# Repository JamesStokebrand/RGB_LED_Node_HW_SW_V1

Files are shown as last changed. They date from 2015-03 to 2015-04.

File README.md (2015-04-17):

RGB LED Controller and Node Project Version 1:

This is the Software/Hardware for the Node.

parts_list:
- Parts list pulled from EagleCAD project.
- Parts list spreadsheet listing quantity, parts numbers and supplier URLs.

src_code:
- CPP source code:
  * Makefile for AVR ATmega328p
  * XBee UART Driver and Communication wrapper
  * Support for AVR sleep and power reduction
  * Software based PWM (Timer based)
  * RGB Node State Machine
  * Color support for RGB and HSL color modes.

pcb_details:
- PCB Top/Bottom PNGs
- Eagle CAD schematic

PCBs are available for order on OSH Park:
https://oshpark.com/shared_projects/6Eqv3vIh

project_case:
- project case files in STL format with associated photos

Further information on this project can be found here:
https://jamesstokebrand.wordpress.com/category/rgb-led-controller-and-node-v1/

14 Mar 2015 - Initial Commit

23 Mar 2015 - Added Schematics and Project Cases 

17 Apr 2015 - Updated source code to use additional sleep methods. Fixed issues with RGB color classes and color conversions.

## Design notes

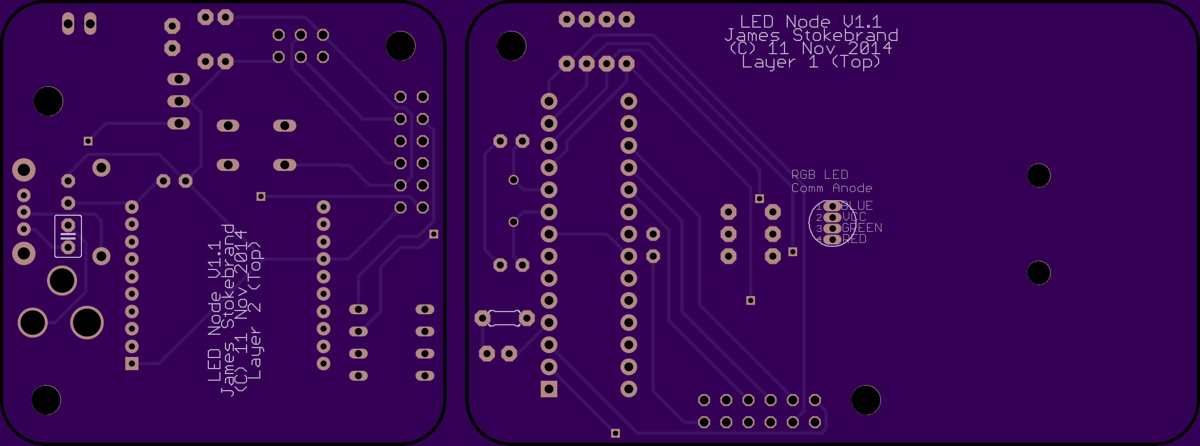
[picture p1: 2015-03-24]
pcb_details/Node_PCB_Top_V1.png

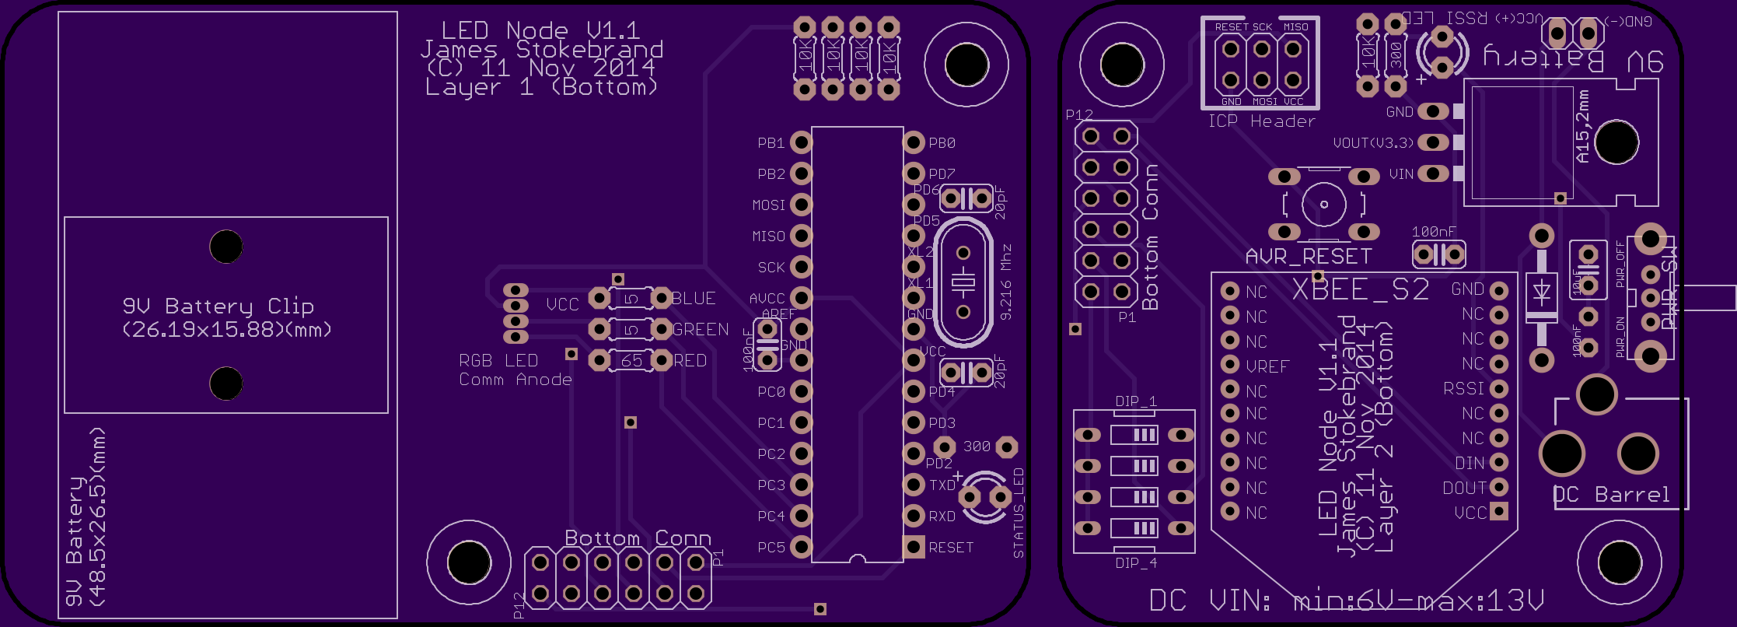
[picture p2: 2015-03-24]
pcb_details/Node_PCB_Bottom_V1.png

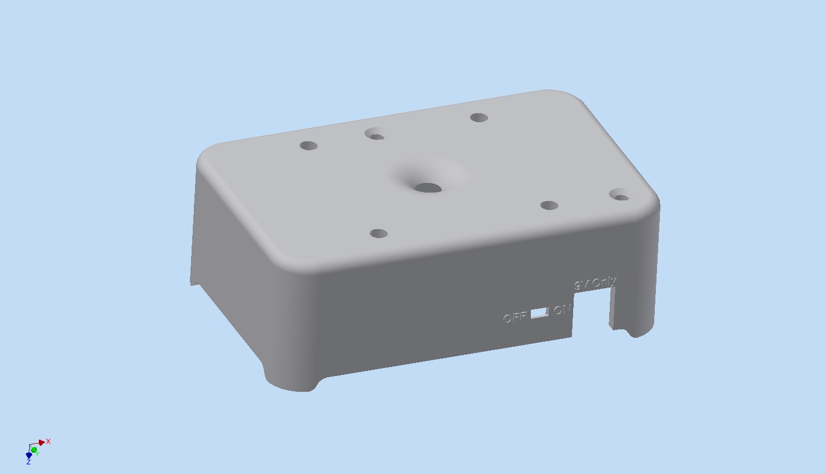
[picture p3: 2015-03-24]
project_case/Node_Shell_V1.jpg

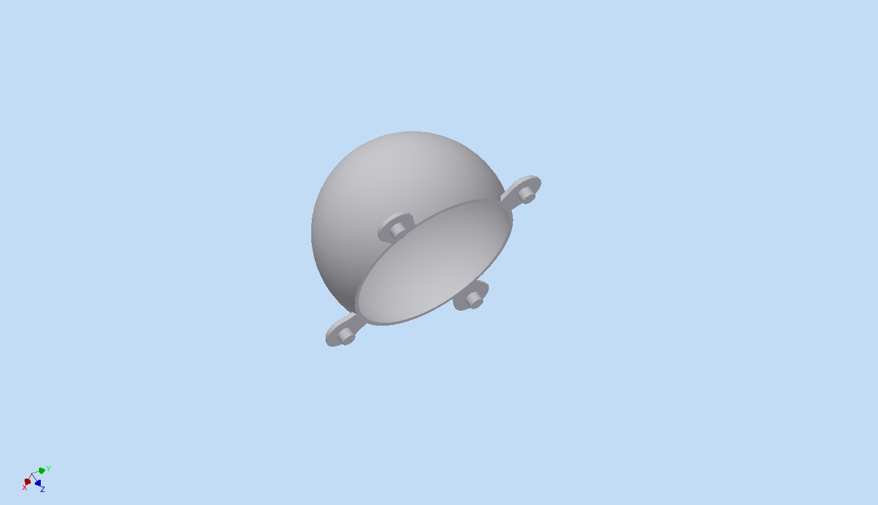
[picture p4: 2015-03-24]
project_case/Node_Globe_V1.jpg

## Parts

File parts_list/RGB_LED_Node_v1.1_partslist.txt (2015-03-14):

Partlist

Exported from RGB_LED_Node_v1.0.brd at 11/11/14 9:02 AM

EAGLE Version 6.6.0 Copyright (c) 1988-2014 CadSoft

Assembly variant: 

Part       Value                   Package        Library                       Position (inch)       Orientation

C1         100nF                   C025-030X050   adafruit                      (5.75 0.99)           MR90
C2         10uF                    C025-030X050   adafruit                      (5.75 1.19)           R270
C3         100nF                   C025-024X044   adafruit                      (3.21 0.95)           R270
C4         20pF                    C025-024X044   adafruit                      (3.85 0.86)           R0
C9         20pf                    C025-024X044   adafruit                      (3.85 1.42)           R0
C13        100nF                   C025-024X044   adafruit                      (5.27 1.24)           R0
CN1        DC Barrel Jack          DCJACK_2MM_PTH adafruit                      (6.2 0.6)             R90
D1         1N4004                  DO41-10        adafruit                      (5.6 1.1)             R90
D2         LED-RGB-CA-THRUDIFFUSE  LED-RGB-THRU   SparkFun-LED                  (2.4 1.05)            MR90
IC1        LD117AV33               TO220L1        v-reg                         (5.4 1.6)             R270
ICP_HEADER                         2X03           pinhead                       (4.7 1.85)            R180
JP1                                2X06           pinhead                       (2.73 0.2)            R180
JP2                                2X06           pinhead                       (4.2 1.37)            R90
JP5                                1X02           pinhead                       (5.7 1.95)            R0
LED7       3mm RED                 LED3MM         adafruit                      (5.28 1.89)           R90
LED8       3mm RED                 LED3MM         adafruit                      (3.91 0.46)           R0
R1         68 Ohm                  0204/5         adafruit                      (2.77 1.1)            R180
R2         5 Ohm                   0204/5         adafruit                      (2.77 1)              R180
R3         10K                     0204/5         adafruit                      (3.33 1.87)           R90
R4         5 Ohm                   0204/5         adafruit                      (2.77 0.9)            R180
R5         10K                     0204/5         adafruit                      (3.42 1.87)           R90
R6         10K                     0204/5         adafruit                      (3.51 1.87)           R90
R7         10K                     0204/5         adafruit                      (3.6 1.87)            R90
R9         10K Ohm                 0204/5         adafruit                      (5.04 1.88)           R90
R14        300 Ohm                 0204/5         adafruit                      (3.88 0.62)           MR180
R21        300 Ohm                 0204/5         adafruit                      (5.13 1.88)           R90
S2         RESET                   B3F-10XX       switch-omron                  (4.9 1.4)             R0
S6         EG1213                  EG1213         adafruit                      (5.95 1.1)            R90
SW1                                EDG-04         special                       (4.29 0.51)           R90
U1         ATMEGA328P-PU-1030050P1 DIP28          OPL_Eagle_Library_Seeed_Sudio (3.5 0.95)            R180
XBEE       XBEE                    XBEE           adafruit                      (5.03 0.63)           R180
Y1          9.216 Mhz              HC49U-V        SparkFun-FreqCtrl             (3.84 1.15)           R90

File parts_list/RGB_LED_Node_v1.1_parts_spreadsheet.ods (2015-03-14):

11/11/14 | RGB LED Node Board V1.1
Count | Part Name/Description | Pins/Pkg | Pin Spacing | Manuf Part # | Supplier | Supplier Part # | Price Ea (~) | Total | URL
1 | 3.3v Voltage Regulator | 3 | 0.1”(2.54mm) | LD1117V33 | Digikey | 497-1491-5-ND | 0.64 | 0.64 | http://www.digikey.com/product-detail/en/LD1117V33/497-1491-5-ND/586012
3 | CAP CER 0.1UF 25V RADIAL (100nF) | 2 | 0.1”(2.54mm) | FK18X7R1E104K | Digikey | 445-8421-ND | 0.29 | 0.87 | http://www.digikey.com/product-detail/en/FK18X7R1E104K/445-8421-ND/2815351
2 | CAP CER 20PF 50V 5% RADIAL | 2 | 0.1”(2.54mm) | C317C200J5G5TA | Digikey | 399-8916-ND | 0.51 | 1.02 | http://www.digikey.com/product-detail/en/C317C200J5G5TA/399-8916-ND/3522973
1 | CAP CER 10UF 25V 10% RADIAL | 2 | 0.1”(2.54mm) | FK16X7R1E106K | Digikey | 445-8351-ND | 0.65 | 0.65 | http://www.digikey.com/product-detail/en/FK16X7R1E106K/445-8351-ND/2815281
1 | CRYSTAL 9.216MHZ 20PF THRU | 2 | 4.8mm | ECS-92.1-20-4X | Digikey | X1096-ND | 0.81 | 0.81 | http://www.digikey.com/product-detail/en/ECS-92.1-20-4X/X1096-ND/827587
1 | LED SS RED DIFFUSED PCB 3MM | 2 | 0.1”(2.54mm) | MV50640 | Digikey | 1080-1100-ND | 0.42 | 0.42 | http://www.digikey.com/product-detail/en/MV50640/1080-1100-ND/2675591
1 | LED SS YELLOW DIFFUSED PCB 3MM | 2 | 0.1”(2.54mm) | MV5374C | Digikey | 1080-1106-ND | 0.46 | 0.46 | http://www.digikey.com/product-detail/en/MV5374C/1080-1106-ND/2675597
2 | RES 300 OHM 1/4W 1% AXIAL | 2 | 0.1”(2.54mm) | RNMF14FTC300R | Digikey | S300CACT-ND | 0.14 | 0.28 | http://www.digikey.com/product-detail/en/RNMF14FTC300R/S300CACT-ND/2617485
1 | SWITCH TACTILE SPST-NO 0.05A 24V | 4 | 6.5mmX4.5mm | B3F-1020 | Digikey | SW402-ND | 0.41 | 0.41 | http://www.digikey.com/product-detail/en/B3F-1020/SW402-ND/44059
1 | SWITCH SLIDE SPDT 30V RT ANGLE | 4 | Various | EG1213 | Digikey | EG1906-ND | 0.58 | 0.58 | http://www.digikey.com/product-detail/en/EG1213/EG1906-ND/101735
1 | ATMEGA328P-PU (IC MCU 8BIT 32KB FLASH 28DIP) | DIP28 | 0.1”(2.54mm) | ATMEGA328P-PU | Digikey | ATMEGA328P-PU-ND | 3.74 | 3.74 | http://www.digikey.com/product-detail/en/ATMEGA328P-PU/ATMEGA328P-PU-ND/1914589
1 | CONN IC SOCKET VERT 28POS TIN | DIP28 | 0.1”(2.54mm) | ED281DT | Digikey | ED3050-5-ND | 0.31 | 0.31 | http://www.digikey.com/product-detail/en/ED281DT/ED3050-5-ND/4147600
1 | DC Barrel Power Jack/connector | 3 | 4.7mm | PJ-002A | Digikey | CP-002A-ND | 0.93 | 0.93 | http://www.digikey.com/product-detail/en/PJ-002A/CP-002A-ND/96962
1 | DIODE GEN PURPOSE 50V 1A DO41 | 2 | N/A | 1N4001-TP | Digikey | 1N4001-TPMSCT-ND | 0.11 | 0.11 | http://www.digikey.com/product-detail/en/1N4001-TP/1N4001-TPMSCT-ND/773688
5 | RES 10K OHM 1/4W 1% AXIAL | 2 | 0.1”(2.54mm) | RNMF14FTC10K0 | Digikey | S10KCACT-ND | 0.14 | 0.7 | http://www.digikey.com/product-detail/en/RNMF14FTC10K0/S10KCACT-ND/2617809
1 | MODULE ZIGBEE W/WIRED ANT | 20 | 0.079”(2mm) | XB24-Z7WIT-004 | Digikey | 602-1098-ND | 17 | 17 | http://www.digikey.com/product-detail/en/XB24-Z7WIT-004/602-1098-ND/1942304
2 | CONN RECEPT 2MM SINGLE STR 10POS (1x10 2mm strip XBEE Socket) | 10 | 0.079”(2mm) | NPPN101BFCN-RC | Digikey | S5751-10-ND | 1.23 | 2.46 | http://www.digikey.com/product-detail/en/NPPN101BFCN-RC/S5751-10-ND/804812
1 | CONN HEADER 6POS 2.54 (2x3) | 2x3 | 0.1”(2.54mm) | 61200621621 | Digikey | 732-5394-ND | 0.82 | 0.82 | http://www.digikey.com/product-detail/en/61200621621/732-5394-ND/4846913
1 | CONN HEADER FMAL 12PS .1" DL TIN (2x6) | 2x6 | 0.1”(2.54mm) | PPTC062LFBN-RC | Digikey | S7074-ND | 0.98 | 0.98 | http://www.digikey.com/product-detail/en/PPTC062LFBN-RC/S7074-ND/810212
1 | Header, straight, 0.1”(2.54mm) pitch, male 5.84mm high (2x36 pin headers) | 2x36 | 0.1”(2.54mm) | 67996-472HLF | Digikey | 609-3494-ND | 1.45 | 1.45 | http://www.digikey.com/product-detail/en/67996-472HLF/609-3494-ND/1486045
1 | 9V SNAP I STYLE 3" WIRE LEADS | 2 | 0.1”(2.54mm) | BS3I | Digikey | BS3I-ND | 0.59 | 0.59 | http://www.digikey.com/product-detail/en/BS3I/BS3I-ND/2439485
1 | SWITCH DIP EXT ACTUATOR 4POS 24V | 8 | 0.1”(2.54mm) | 1825057-3 | Digikey | 450-1364-ND | 0.76 | 0.76 | http://www.digikey.com/product-detail/en/1825057-3/450-1364-ND/969174
1 | HOLDER BATTERY 9 VOLT STEEL | N/A | N/A | 71 | Digikey | 71K-ND | 0.42 | 0.42 | http://www.digikey.com/product-detail/en/71/71K-ND/1532224
2 | RES 5.1 OHM 1/4W 5% CF MINI | 2 | 1.7mm | CFM14JT5R10 | Digikey | S5.1QCT-ND | 0.1 | 0.2 | http://www.digikey.com/product-detail/en/CFM14JT5R10/S5.1QCT-ND/2617777
1 | RES 68 OHM 1/4W 1% AXIAL | 2 | 1.7mm | RNMF14FTC68R0 | Digikey | S68CACT-ND | 0.14 | 0.14 | http://www.digikey.com/product-detail/en/RNMF14FTC68R0/S68CACT-ND/2617528
1 | LED - RGB Diffused Common Anode | 4 | UNK | COM-10821 | Sparkfun | COM-10821 | 1.95 | 1.95 | https://www.sparkfun.com/products/10821
 | On Hand |  |  |  |  |  |  | 38.7
 | Ordered from Digikey
 | Updated parts list for RGB LED Node Board V1.1
 | - Removed four 2K Resistors and replaced with four 10K resistors.
 | NOTE : Maybe replace the 300 Ohm with 220 Ohm to better match the LEDs.!
 | Something like this:
 | RES 220 OHM 1/8W 5% CF AXIAL | 2 | 0.1”(2.54mm) | CF18JT220R | Digikey | CF18JT220RCT-ND | 0.1 |  | http://www.digikey.com/product-detail/en/CF18JT220R/CF18JT220RCT-ND/2022726

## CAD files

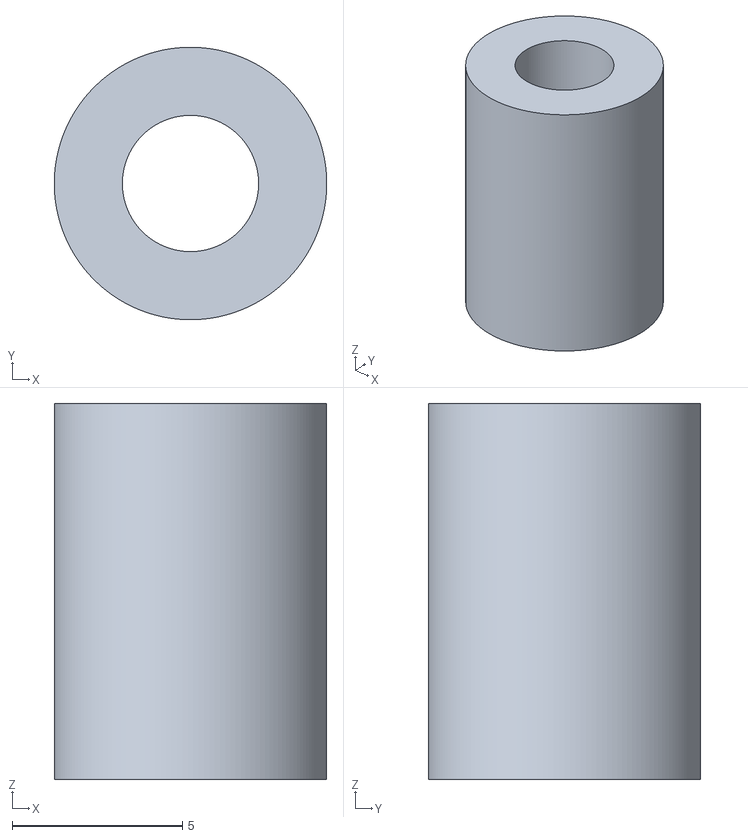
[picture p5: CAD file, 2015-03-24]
project_case/PCB_Spacer.stl
8.00 x 8.00 x 11.0

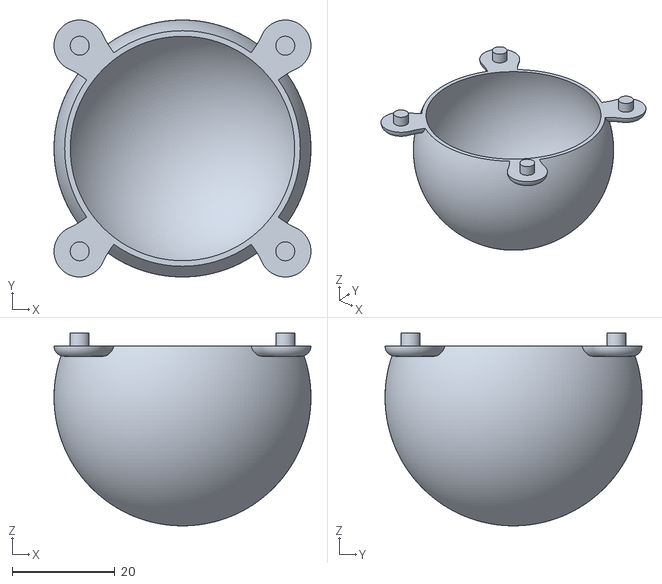
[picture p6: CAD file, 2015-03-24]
project_case/Node_Globe_V1.stl
50.0 x 50.0 x 37.5

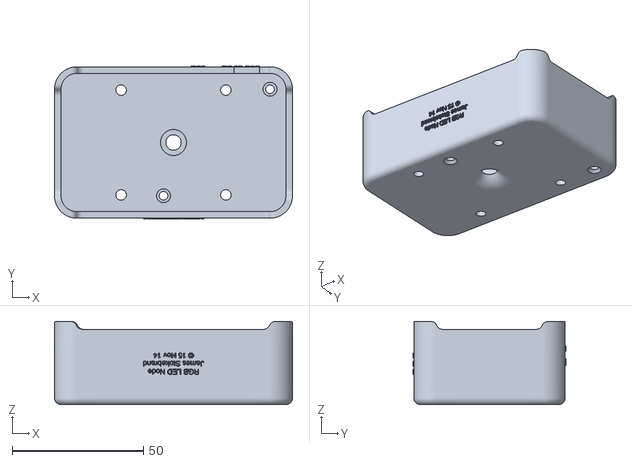
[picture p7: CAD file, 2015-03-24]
project_case/Node_Shell_V1.stl
90.8 x 58.5 x 31.7

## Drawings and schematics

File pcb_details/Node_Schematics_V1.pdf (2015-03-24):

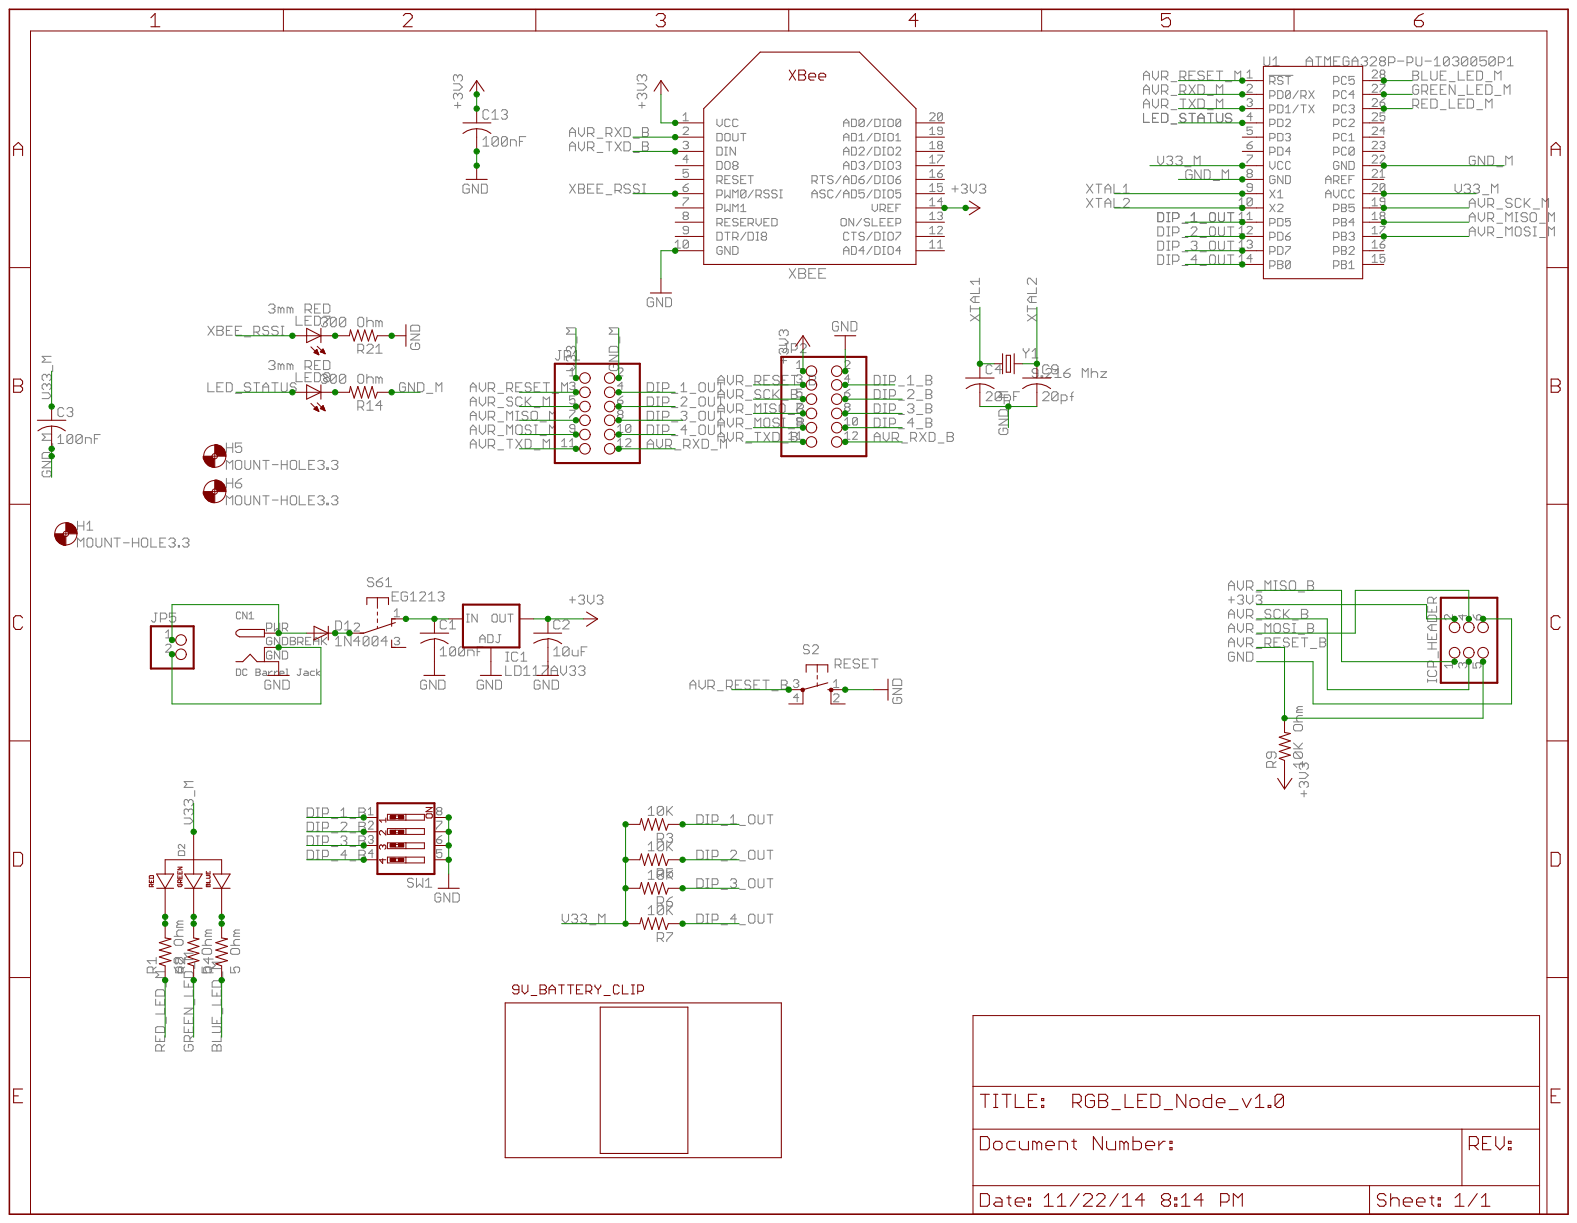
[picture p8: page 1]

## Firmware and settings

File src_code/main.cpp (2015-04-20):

/****************************************************
    RGB LED Node v1 hardware

    File:   main.cpp
    Author: James Stokebrand
    jamesstokebrand AT gmail DOT com
	
    main.cpp file is part of the RGB LED Controller and Node 
     version 1 hardware project.

    This file contains the main() method and the forever loop.  It 
     creates the RGB Node State machine and the code to sleep the AVR
     chip.
     
    Copyright (C) 2015 - James Stokebrand - 2015 Mar 12

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
    Rev History:
     When         Who                Description of change
    -----------  ----------         ------------------------
    2014 Nov 18  James Stokebrand   Initial creation.

*****************************************************/

/*****************************************************

// This is the ATmega328p fuse settings for the project

AVR Chip Fuses:

--- FUSES ---
BODLEVEL    = DISABLED
RSTDISBL    = [ ]
DWEN        = [ ]
SPIEN       = [X]
WDTON       = [ ]
EESAVE      = [ ]
BOOTSZ      = 2048W_3800
BOOTRST     = [ ]
CKDIV8      = [ ]
CKOUT       = [ ]
SUT_CKSEL   = INTRCOSC_8MHZ_6CK_14CK_0MS

EXTENDED    = 0xFF (valid)
HIGH        = 0xD9 (valid)
LOW         = 0xC2 (valid)

--- LOCK BITS ---
LB      = NO_LOCK
BLB0    = NO_LOCK
BLB1    = NO_LOCK

LOCKBIT = 0xFF (valid)

*****************************************************/

#include <avr/io.h>
#include <util/delay.h>
#include <avr/interrupt.h>

#ifndef NEW_H
#include "new.h"
#endif

#ifndef RGBConverter_h
#include "RGBConverter.h"
#endif

#ifndef _RGB_LED_CLASS_H_
#include "rgb_led_class.h"
#endif

#ifndef _EVENT_QUEUE_H_
#include "event_queue.h"
#endif

#ifndef _RGB_NODE_STATE_MACHINE_H_
#include "rgb_node_state_machine.h"
#endif

#ifndef _MCU_SLEEP_CLASS_H_
#include "mcu_sleep_class.h"
#endif


int main(void)
{
    // Enable MCU sleep
    mcu_sleep_class::getInstance()->EnableSleep();

    // Idle is the default power mode ... but set it anyway.
    mcu_sleep_class::getInstance()->SetSleepMode(mcu_sleep_class::E_MCU_SLEEP_MODE_IDLE);

    // Try to save more power.  Turn off these pins.
    mcu_sleep_class::getInstance()->SetInputAndPullupResistor(IOPinDefines::E_PinDef::E_PIN_PD3);
    mcu_sleep_class::getInstance()->SetInputAndPullupResistor(IOPinDefines::E_PinDef::E_PIN_PD4);
    mcu_sleep_class::getInstance()->SetInputAndPullupResistor(IOPinDefines::E_PinDef::E_PIN_PB6);
    mcu_sleep_class::getInstance()->SetInputAndPullupResistor(IOPinDefines::E_PinDef::E_PIN_PB7);
    mcu_sleep_class::getInstance()->SetInputAndPullupResistor(IOPinDefines::E_PinDef::E_PIN_PC2);
    mcu_sleep_class::getInstance()->SetInputAndPullupResistor(IOPinDefines::E_PinDef::E_PIN_PC1);
    mcu_sleep_class::getInstance()->SetInputAndPullupResistor(IOPinDefines::E_PinDef::E_PIN_PC0);
    mcu_sleep_class::getInstance()->SetInputAndPullupResistor(IOPinDefines::E_PinDef::E_PIN_PB2);
    mcu_sleep_class::getInstance()->SetInputAndPullupResistor(IOPinDefines::E_PinDef::E_PIN_PB1);

    // MCU Programming header.   Only used when programming.  Turn these off also.
    mcu_sleep_class::getInstance()->SetInputAndPullupResistor(IOPinDefines::E_PinDef::E_PIN_PB5);
    mcu_sleep_class::getInstance()->SetInputAndPullupResistor(IOPinDefines::E_PinDef::E_PIN_PB4);
    mcu_sleep_class::getInstance()->SetInputAndPullupResistor(IOPinDefines::E_PinDef::E_PIN_PB3);

    // Event queue 
    EventQueue event_queue;

    // Init the Node state machine
    rgb_node_state_machine RGB_Node(&event_queue);

    // RGB Node class has read the 4 pin DIP.  The pins are no longer needed so enable
    //  power savings.
    mcu_sleep_class::getInstance()->SetInputAndPullupResistor(IOPinDefines::E_PinDef::E_PIN_PD5);
    mcu_sleep_class::getInstance()->SetInputAndPullupResistor(IOPinDefines::E_PinDef::E_PIN_PD6);
    mcu_sleep_class::getInstance()->SetInputAndPullupResistor(IOPinDefines::E_PinDef::E_PIN_PD7);
    mcu_sleep_class::getInstance()->SetInputAndPullupResistor(IOPinDefines::E_PinDef::E_PIN_PB0);

    sei();

    event_element_class anEvent;

    // Forever is a long time.
    for (;;) 
    {
        if (event_queue.Dequeue(anEvent))
        {
            // Process events throught the RGB Node state machine
            RGB_Node.process(anEvent);
        } else {

            // Nothing in the queue ... go to sleep
            mcu_sleep_class::getInstance()->GoMakeSleepNow();
        }
    }

    return 0;
}

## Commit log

2015-03-14 RGB LED Controller and Node Project Version 1:
    This is the Software/Hardware for the Node.
    parts_list:
    - Parts list pulled from EagleCAD project.
    - Parts list spreadsheet listing quantity, parts numbers and supplier URLs.
    src_code:
    - CPP source code:
    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
    [RGB_LED_Node_v1.1_parts_spreadsheet.ods]
2015-03-24 Added pcb_details directory with Schematic and Top/Bottom representations.
    Added project_case directory with:
    Node_Globe_V1.stl - Globe topper
    Node_Shell_V1.stl - Case
    PCB_Spacer.stl
    [Node_Globe_V1.stl, Node_Shell_V1.stl, PCB_Spacer.stl]
2015-04-17 Moved InterruptSubjectPinIntr from Pin class to HAL interrupt class. And moved the instance to button_class.h Changed files: - pin_class.h/cpp - hal_interrupts.h/cpp - button_class.h
    Moved some state_class methods from header to new cpp file.
    Changed added/files:
    - state_class.h/cpp
    - Makefile
    Updated event_listing.h for new events as per new development.
    Updated MCU sleep methods and updated/added them to main.cpp:
    Changed files:
    - mcu_sleep_class.h/cpp
    - main.cpp
    Updated RGB controller state machine for missing Node feedback events:
    Changed file: rgb_controller_state_machine.h
    Updated RGB conversaion code to compile out unused HSV methods. Updated
    RGBConverter to verify HSV conversi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
    [main.cpp]
2015-04-20 Updated mcu_sleep_class to allow adjusting the sleep mode. Set the sleep mode as "IDLE". Set the 4 pin DIP pins as input/enable pullup to save power in main.cpp. Changed files: main.cpp mcu_sleep_cla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
    Updated header comments on the state_class.h/cpp
2015-04-20 Updated state machine to enable/disable Awake Status LED as per a command from the controller. Changed files: event_listing.h rgb_node_state_machine.h
    Updated main.cpp to fix comments and add sleeping the programming
    header pins.
    Fixed a comment in mcu_sleep_class.cpp.
    [main.cpp]

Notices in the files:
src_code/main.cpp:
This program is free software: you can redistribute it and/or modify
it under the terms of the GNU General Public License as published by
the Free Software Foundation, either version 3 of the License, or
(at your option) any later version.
